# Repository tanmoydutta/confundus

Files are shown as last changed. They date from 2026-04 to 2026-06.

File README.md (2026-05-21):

# Confundus, an LIC Super Capacitor Trinket
Confundus powers an MCU driven LED matrix by means of using an LIC Super Capacitor as it's power source.

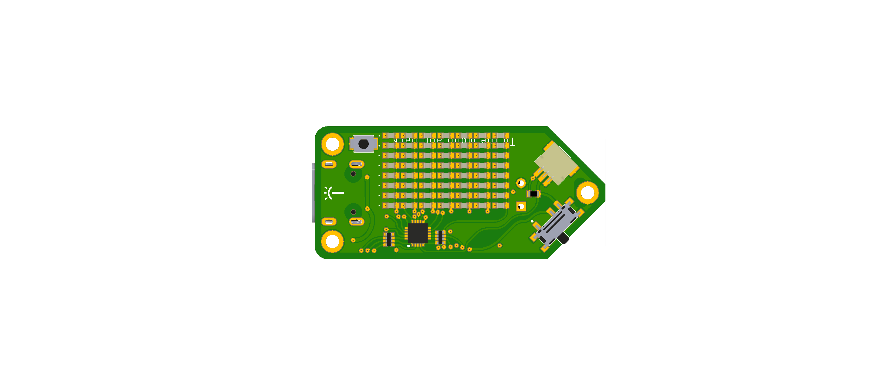
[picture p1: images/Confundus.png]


It also has a matching 3D printed box to house the circuit as a keychain hanger or as an ornament that hangs next to an ID card

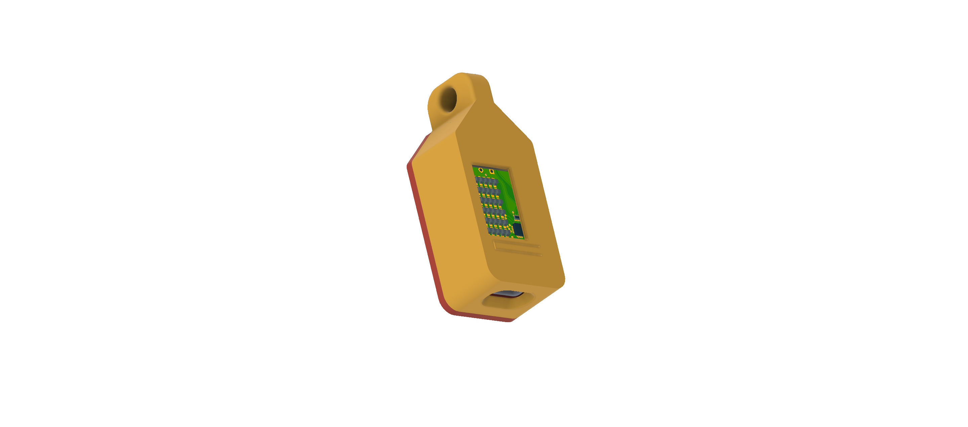
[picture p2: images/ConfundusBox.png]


Some of the actual view of the project - 
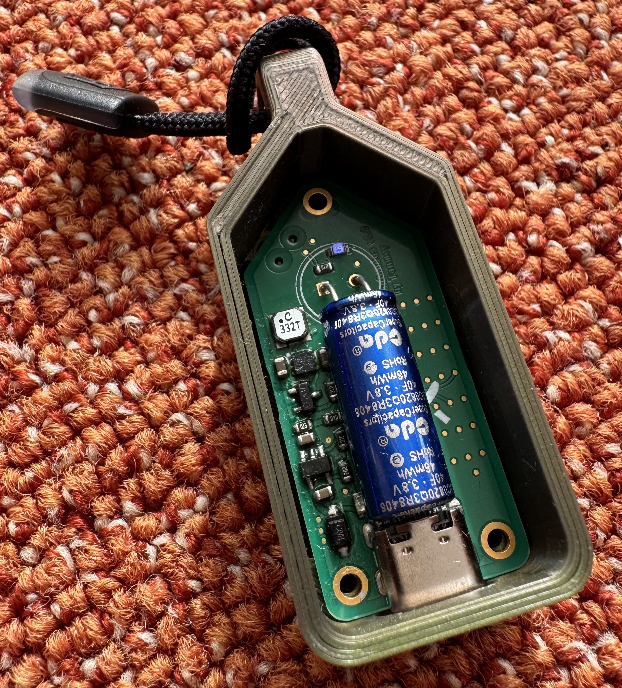
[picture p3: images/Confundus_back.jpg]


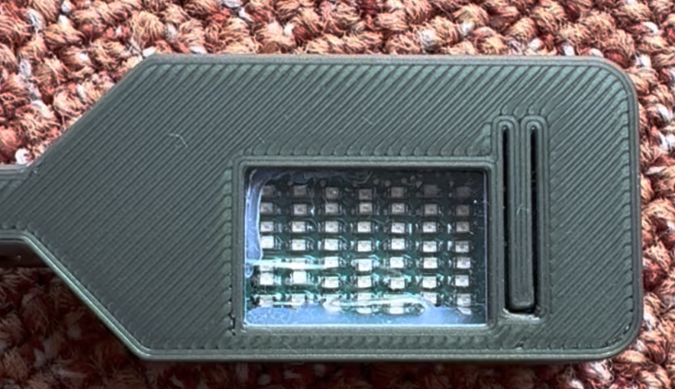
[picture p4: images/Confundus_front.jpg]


This project is certified as Open Source Hardware - 
<p align="center">
  <a href="https://certification.oshwa.org/nl000043.html">
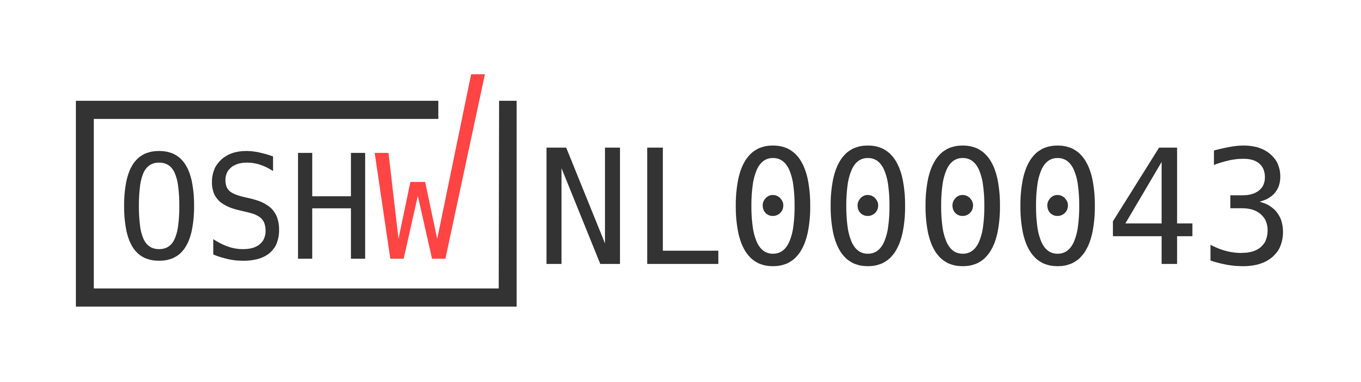
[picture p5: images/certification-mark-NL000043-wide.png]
OSHWA OSHWA Certification
    
  </a>
</p>



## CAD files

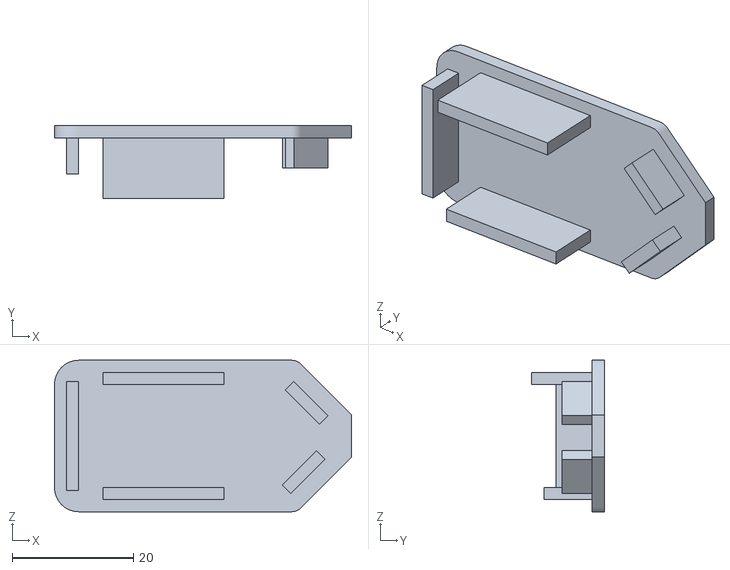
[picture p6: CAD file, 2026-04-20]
3D_Models/ConfundusCover.stl
49.0 x 12.0 x 25.0

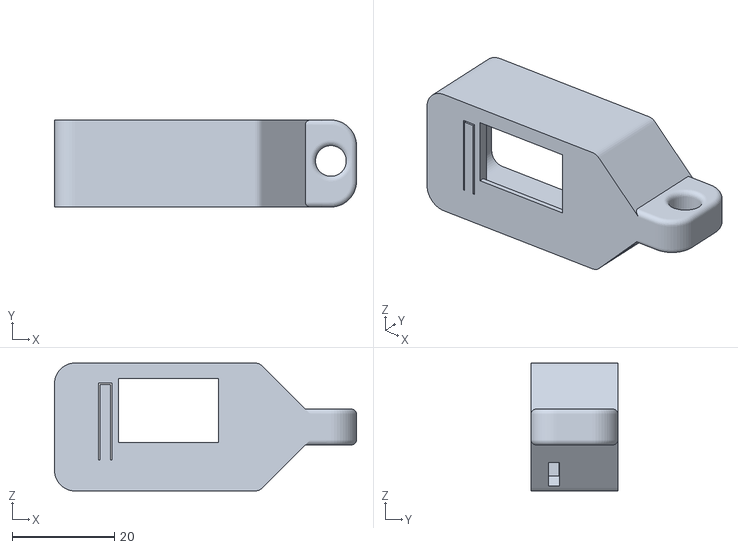
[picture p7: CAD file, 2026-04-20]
3D_Models/ConfundusHolder.stl
59.0 x 17.0 x 25.0

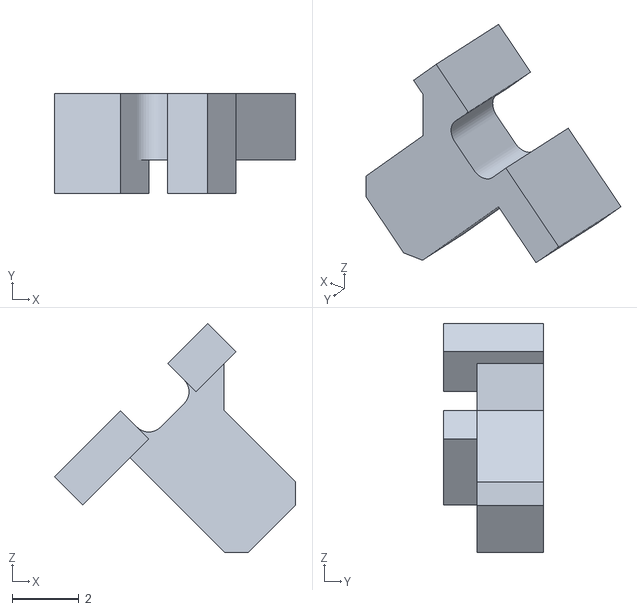
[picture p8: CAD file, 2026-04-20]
3D_Models/PowerButton.stl
7.23 x 3.00 x 6.88

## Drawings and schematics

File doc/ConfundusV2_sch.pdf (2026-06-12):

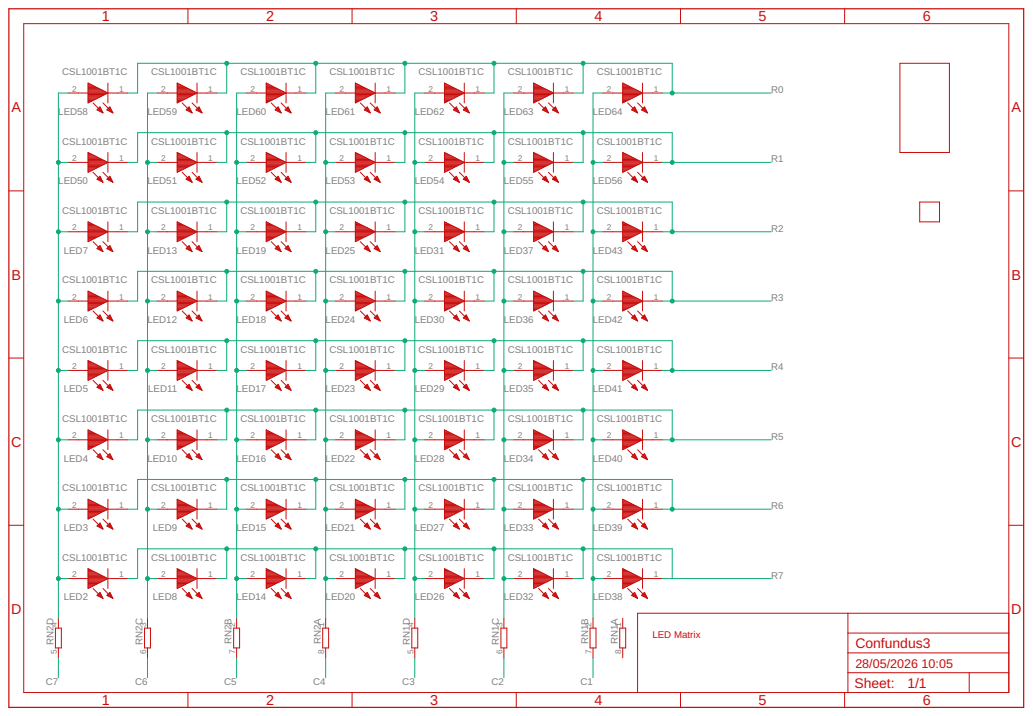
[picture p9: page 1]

LED Matrix

Sheet: 1/1

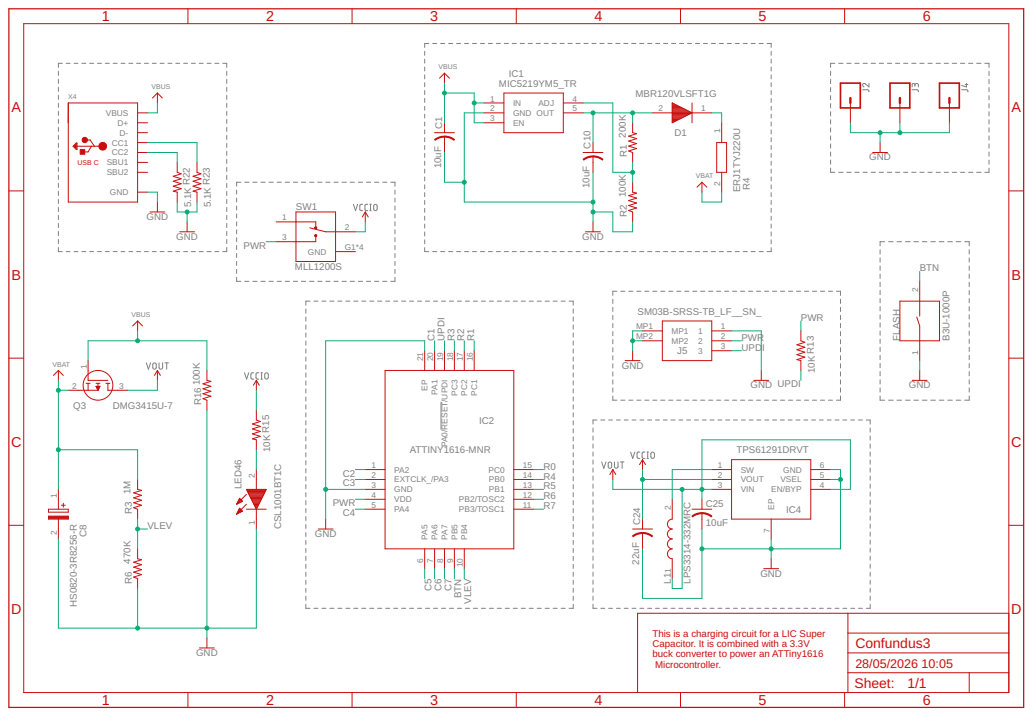
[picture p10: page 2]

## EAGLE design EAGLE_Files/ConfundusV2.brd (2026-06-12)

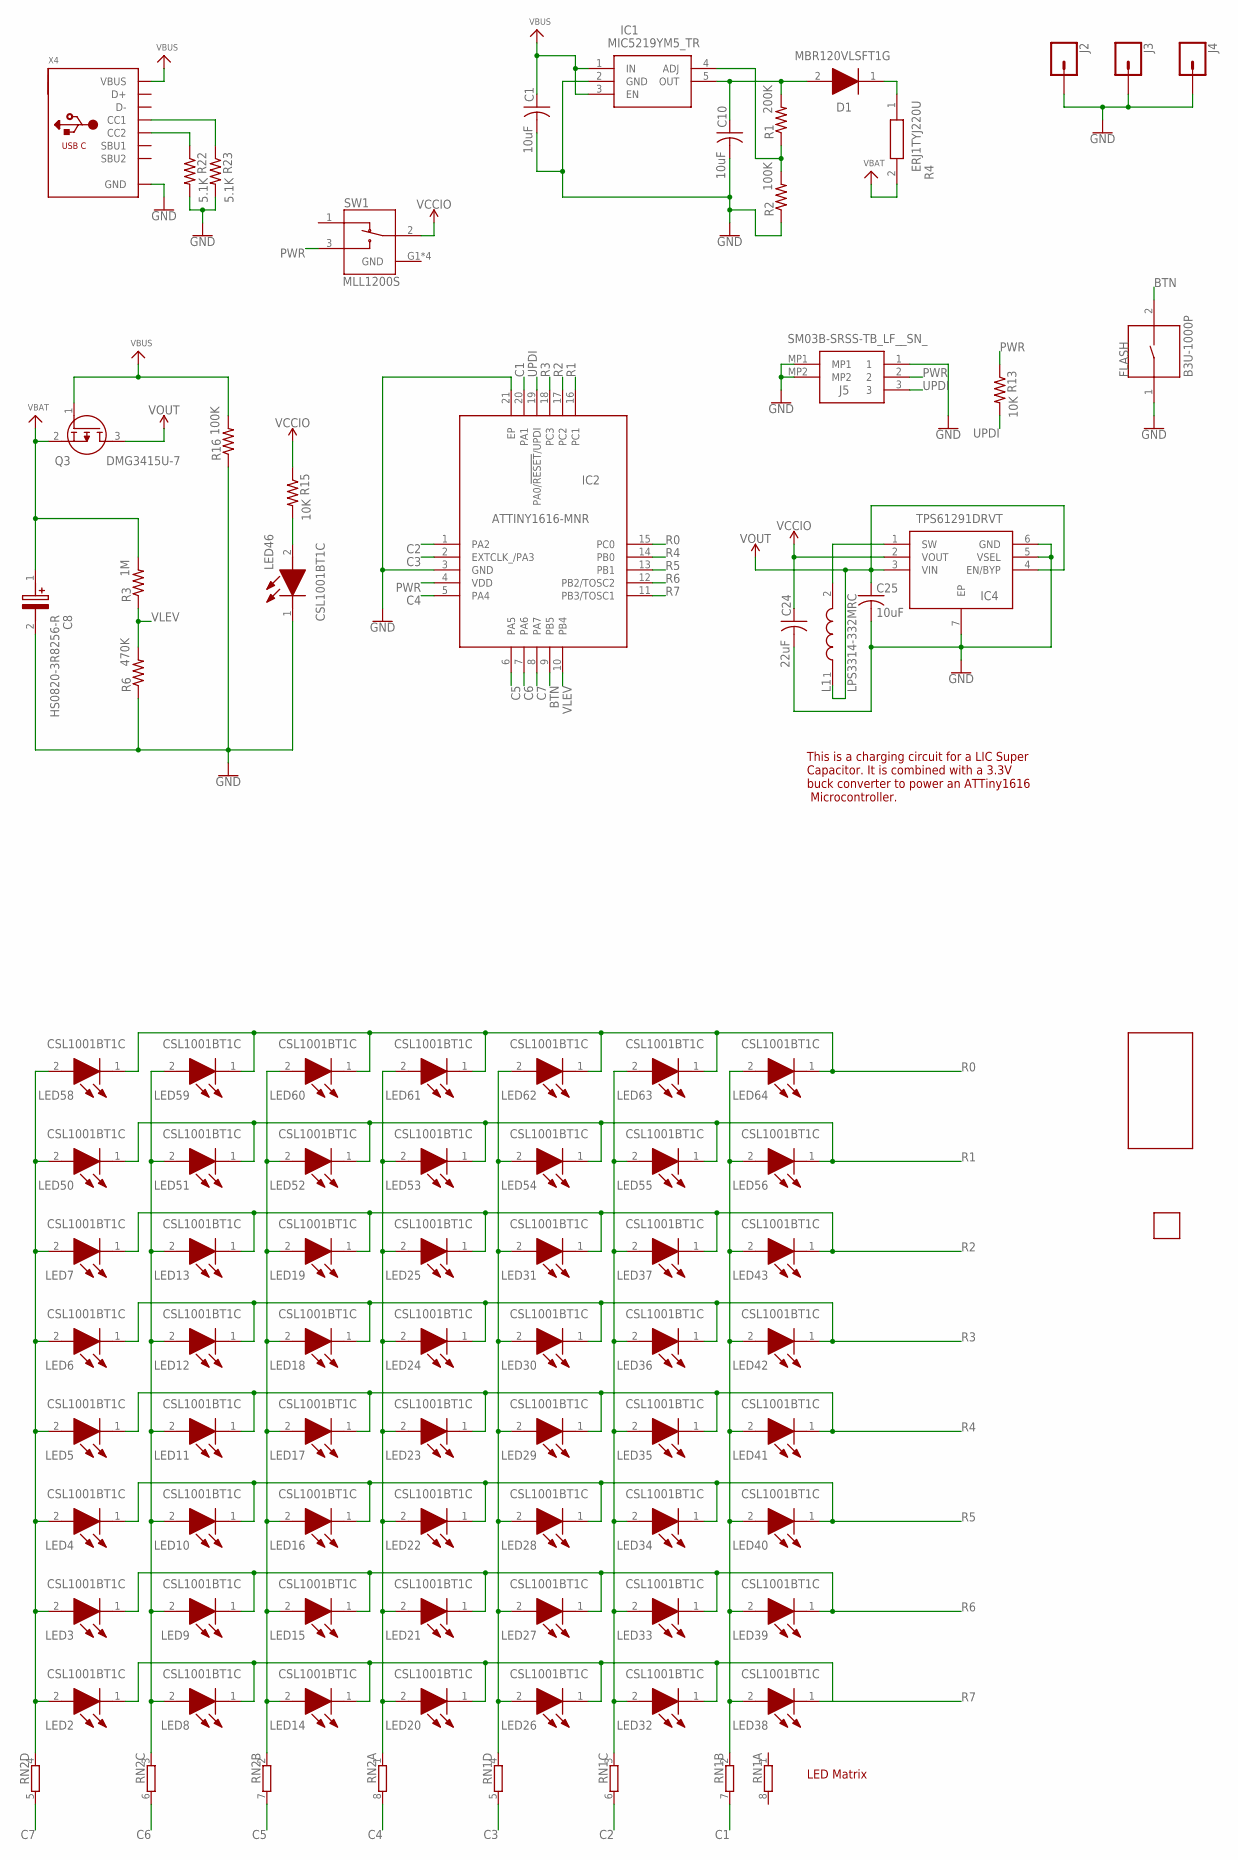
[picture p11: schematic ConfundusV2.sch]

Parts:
C1, C10, C25: 10uF; C0402
C8: HS0820-3R8256-R; CAPPRD350W65D850H2200
C24: 22uF; C0402
D1: MBR120VLSFT1G; SODFL3616X98N
FLASH: B3U-1000P; SW_B3U-1000P
IC1: MIC5219YM5_TR; SOT95P280X145-5N
IC2: ATTINY1616-MNR; QFN40P300X300X90-21N
IC4: TPS61291DRVT; SON65P200X200X80-7N
J2, J3, J4: CONN_01PTH_2MM; 1X01_2MM
J5: SM03B-SRSS-TB_LF__SN_; SM03BSRSSTBLFSN
L1: LPS3314-332MRC; LPS3314332MRC
LED2, LED3, LED4, LED5, LED6, LED7, LED8, LED9, LED10, LED11, LED12, LED13, LED14, LED15, LED16, LED17, LED18, LED19, LED20, LED21, LED22, LED23, LED24, LED25, LED26, LED27, LED28, LED29, LED30, LED31, LED32, LED33, LED34, LED35, LED36, LED37, LED38, LED39, LED40, LED41, LED42, LED43, LED46, LED50, LED51, LED52, LED53, LED54, LED55, LED56, LED58, LED59, LED60, LED61, LED62, LED63, LED64: CSL1001BT1C
Q3: DMG3415U-7; SOT96P240X100-3N
R1: 200K; R0402
R2, R16: 100K; R0402
R3: 1M; R0402
R4: ERJ1TYJ220U; ERJ1TRQF1R0U
R6: 470K; R0402
R13, R15: 10K; R0402
R22, R23: 5.1K; R0402
RN1, RN2: 4R-N0402ARV341; 4X0402ARV341
SW1: MLL1200S; SW_MLL1200S
U$1: SMARTT
U$2: SMARTT_SMALL
X4: MICROBUILDER_USB_C; MICROBUILDER_USB_C_CUSB31-CFM2AX-01-X

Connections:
BTN: FLASH.2, IC2.9 (PB5)
C1: IC2.20 (PA1), RN1.7 (2)
C2: IC2.1 (PA2), RN1.6 (2)
C3: IC2.2 (EXTCLK_/PA3), RN1.5 (2)
C4: IC2.5 (PA4), RN2.8 (2)
C5: IC2.6 (PA5), RN2.7 (2)
C6: IC2.7 (PA6), RN2.6 (2)
C7: IC2.8 (PA7), RN2.5 (2)
GND: C1.2, C8.2 (-), C10.2, C24.2, C25.2, FLASH.1, IC1.2 (GND), IC2.3 (GND), IC2.21 (EP), IC4.5 (VSEL), IC4.6 (GND), IC4.7 (EP), J2.1, J3.1, J4.1, J5.1, J5.MP1, J5.MP2, LED46.1 (K), R2.1, R6.1, R16.1, R22.2, R23.2, SW1.G1 (GND), SW1.G2 (GND), SW1.G3 (GND), SW1.G4 (GND), X4.A1B12 (GND), X4.B1A12 (GND)
unnamed: LED38.2 (A), LED39.2 (A), LED40.2 (A), LED41.2 (A), LED42.2 (A), LED43.2 (A), LED56.2 (A), LED64.2 (A), RN1.2 (1)
unnamed: LED32.2 (A), LED33.2 (A), LED34.2 (A), LED35.2 (A), LED36.2 (A), LED37.2 (A), LED55.2 (A), LED63.2 (A), RN1.3 (1)
unnamed: LED26.2 (A), LED27.2 (A), LED28.2 (A), LED29.2 (A), LED30.2 (A), LED31.2 (A), LED54.2 (A), LED62.2 (A), RN1.4 (1)
unnamed: LED20.2 (A), LED21.2 (A), LED22.2 (A), LED23.2 (A), LED24.2 (A), LED25.2 (A), LED53.2 (A), LED61.2 (A), RN2.1
unnamed: LED14.2 (A), LED15.2 (A), LED16.2 (A), LED17.2 (A), LED18.2 (A), LED19.2 (A), LED52.2 (A), LED60.2 (A), RN2.2 (1)
unnamed: LED8.2 (A), LED9.2 (A), LED10.2 (A), LED11.2 (A), LED12.2 (A), LED13.2 (A), LED51.2 (A), LED59.2 (A), RN2.3 (1)
unnamed: LED2.2 (A), LED3.2 (A), LED4.2 (A), LED5.2 (A), LED6.2 (A), LED7.2 (A), LED50.2 (A), LED58.2 (A), RN2.4 (1)
unnamed: R22.1, X4.B5 (CC2)
unnamed: R23.1, X4.A5 (CC1)
unnamed: C10.1, D1.2 (A), IC1.5 (OUT), R1.2
unnamed: IC1.4 (ADJ), R1.1, R2.2
unnamed: D1.1 (K), R4.1
unnamed: IC4.1 (SW), L1.2
unnamed: LED46.2 (A), R15.2
PWR: IC2.4 (VDD), J5.2, R13.1, SW1.3
R0: IC2.15 (PC0), LED58.1 (K), LED59.1 (K), LED60.1 (K), LED61.1 (K), LED62.1 (K), LED63.1 (K), LED64.1 (K)
R1: IC2.16 (PC1), LED50.1 (K), LED51.1 (K), LED52.1 (K), LED53.1 (K), LED54.1 (K), LED55.1 (K), LED56.1 (K)
R2: IC2.17 (PC2), LED7.1 (K), LED13.1 (K), LED19.1 (K), LED25.1 (K), LED31.1 (K), LED37.1 (K), LED43.1 (K)
R3: IC2.18 (PC3), LED6.1 (K), LED12.1 (K), LED18.1 (K), LED24.1 (K), LED30.1 (K), LED36.1 (K), LED42.1 (K)
R4: IC2.14 (PB0), LED5.1 (K), LED11.1 (K), LED17.1 (K), LED23.1 (K), LED29.1 (K), LED35.1 (K), LED41.1 (K)
R5: IC2.13 (PB1), LED4.1 (K), LED10.1 (K), LED16.1 (K), LED22.1 (K), LED28.1 (K), LED34.1 (K), LED40.1 (K)
R6: IC2.12 (PB2/TOSC2), LED3.1 (K), LED9.1 (K), LED15.1 (K), LED21.1 (K), LED27.1 (K), LED33.1 (K), LED39.1 (K)
R7: IC2.11 (PB3/TOSC1), LED2.1 (K), LED8.1 (K), LED14.1 (K), LED20.1 (K), LED26.1 (K), LED32.1 (K), LED38.1 (K)
UPDI: IC2.19 (PA0/!RESET!/UPDI), J5.3, R13.2
VBAT: C8.1 (+), Q3.2 (S), R3.2, R4.2
VBUS: C1.1, IC1.1 (IN), IC1.3 (EN), Q3.1 (G), R16.2, X4.A4B9 (VBUS), X4.B4A9 (VBUS)
VCCIO: C24.1, IC4.2 (VOUT), R15.1, SW1.2
VLEV: IC2.10 (PB4), R3.1, R6.2
VOUT: C25.1, IC4.3 (VIN), IC4.4 (EN/BYP), L1.1, Q3.3 (D)

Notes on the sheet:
LED Matrix
This is a charging circuit for a LIC Super Capacitor. It is combined with a 3.3V buck converter to power an ATTiny1616 Microcontroller.

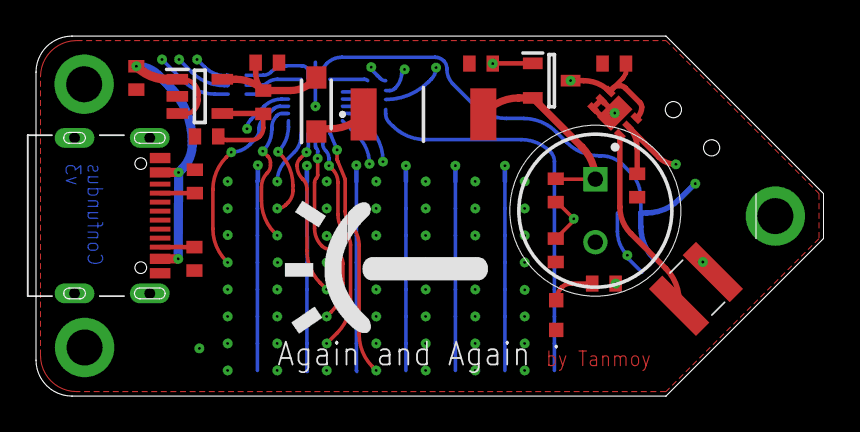
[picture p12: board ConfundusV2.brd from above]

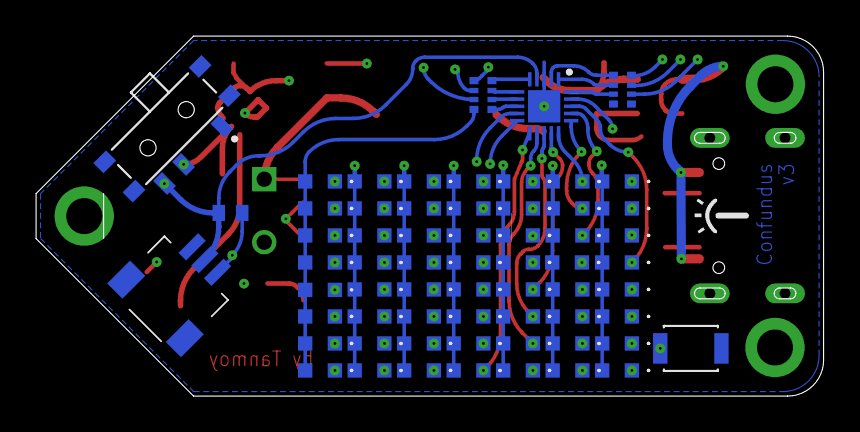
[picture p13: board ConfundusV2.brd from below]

Board: 6 copper layers, 43.7 x 20.0 mm, 89 parts (63 on the bottom side), 38 nets.

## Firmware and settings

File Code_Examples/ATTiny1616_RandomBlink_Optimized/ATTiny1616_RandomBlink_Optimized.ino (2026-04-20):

#include <avr/sleep.h>
#include <avr/interrupt.h>

// Row pins
const uint8_t rowPins[8] = {
  PIN_PC0, PIN_PC1, PIN_PC2, PIN_PC3,
  PIN_PB0, PIN_PB1, PIN_PB2, PIN_PB3
};

// Column pin
const uint8_t colPin = PIN_PA1;

volatile bool wakeFlag = false;

void setup() {
  allHiZ();

  ADC0.CTRLA &= ~ADC_ENABLE_bm;
  AC0.CTRLA  &= ~AC_ENABLE_bm;

  randomSeed(analogRead(0));

  setupRTC();

  set_sleep_mode(SLEEP_MODE_PWR_DOWN);
}

void loop() {

  if (!wakeFlag) {
    sleep_mode();
  }

  wakeFlag = false;

  // Let boost stabilize
  delay(1);

  // ✨ Burst of sparkles
  for (uint8_t i = 0; i < 4; i++) {

    uint8_t r = random(0, 8);

    lightOne(r);
    delay(5);     // ON time

    allHiZ();
    delay(20);    // short gap between sparkles
  }
}

// Turn on one LED
void lightOne(uint8_t row) {
  allHiZ();

  pinMode(colPin, OUTPUT);
  digitalWrite(colPin, HIGH);

  pinMode(rowPins[row], OUTPUT);
  digitalWrite(rowPins[row], LOW);
}

// Hi-Z all pins
void allHiZ() {
  pinMode(colPin, INPUT);

  for (uint8_t i = 0; i < 8; i++) {
    pinMode(rowPins[i], INPUT);
  }
}

// RTC setup (~2 sec)
void setupRTC() {
  while (RTC.STATUS > 0);

  RTC.CLKSEL = RTC_CLKSEL_INT1K_gc;
  RTC.PITINTCTRL = RTC_PI_bm;

  RTC.PITCTRLA = RTC_PERIOD_CYC2048_gc | RTC_PITEN_bm;

  sei();
}

ISR(RTC_PIT_vect) {
  RTC.PITINTFLAGS = RTC_PI_bm;
  wakeFlag = true;
}

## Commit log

2026-04-20 Adding directory structure
    [Confundus2.brd, Confundus2.sch, ConfundusCover.stl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]
2026-05-05 Update README with details on 3D printed box
    Added information about the 3D printed box for the circuit.
2026-05-14 Adjustement to the charging circuit
    [Confundus.brd, Confundus.sch, ConfundusV2.brd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]
2026-06-12 Updating the circuit adjustments for introduction of a Schottky diode
    [Confundus.brd, Confundus.sch, ConfundusV2.brd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]

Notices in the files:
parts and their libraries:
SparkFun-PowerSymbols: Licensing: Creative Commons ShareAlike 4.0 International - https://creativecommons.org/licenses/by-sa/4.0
